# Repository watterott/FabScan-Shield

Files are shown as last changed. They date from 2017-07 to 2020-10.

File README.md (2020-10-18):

# FabScan-Shield
The FabScan-Shield is a plug-on module for Arduino to drive Stepper and Servo Motors or to build a 3D Laser Scanner.

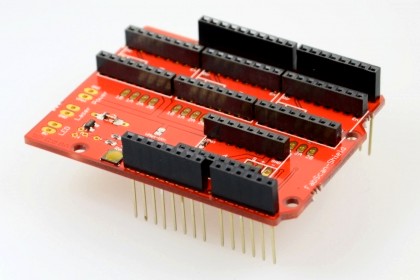
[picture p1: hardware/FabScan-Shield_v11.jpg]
FabScan-Shield


* Drive up to 4 stepper motors (requires Pololu A4988 or StepStick) or servo motors
* Open-Source and released under the [Creative Commons Attribution Share-Alike License](https://creativecommons.org/licenses/by-sa/4.0/).
* **[Documentation on learn.watterott.com](https://learn.watterott.com)**

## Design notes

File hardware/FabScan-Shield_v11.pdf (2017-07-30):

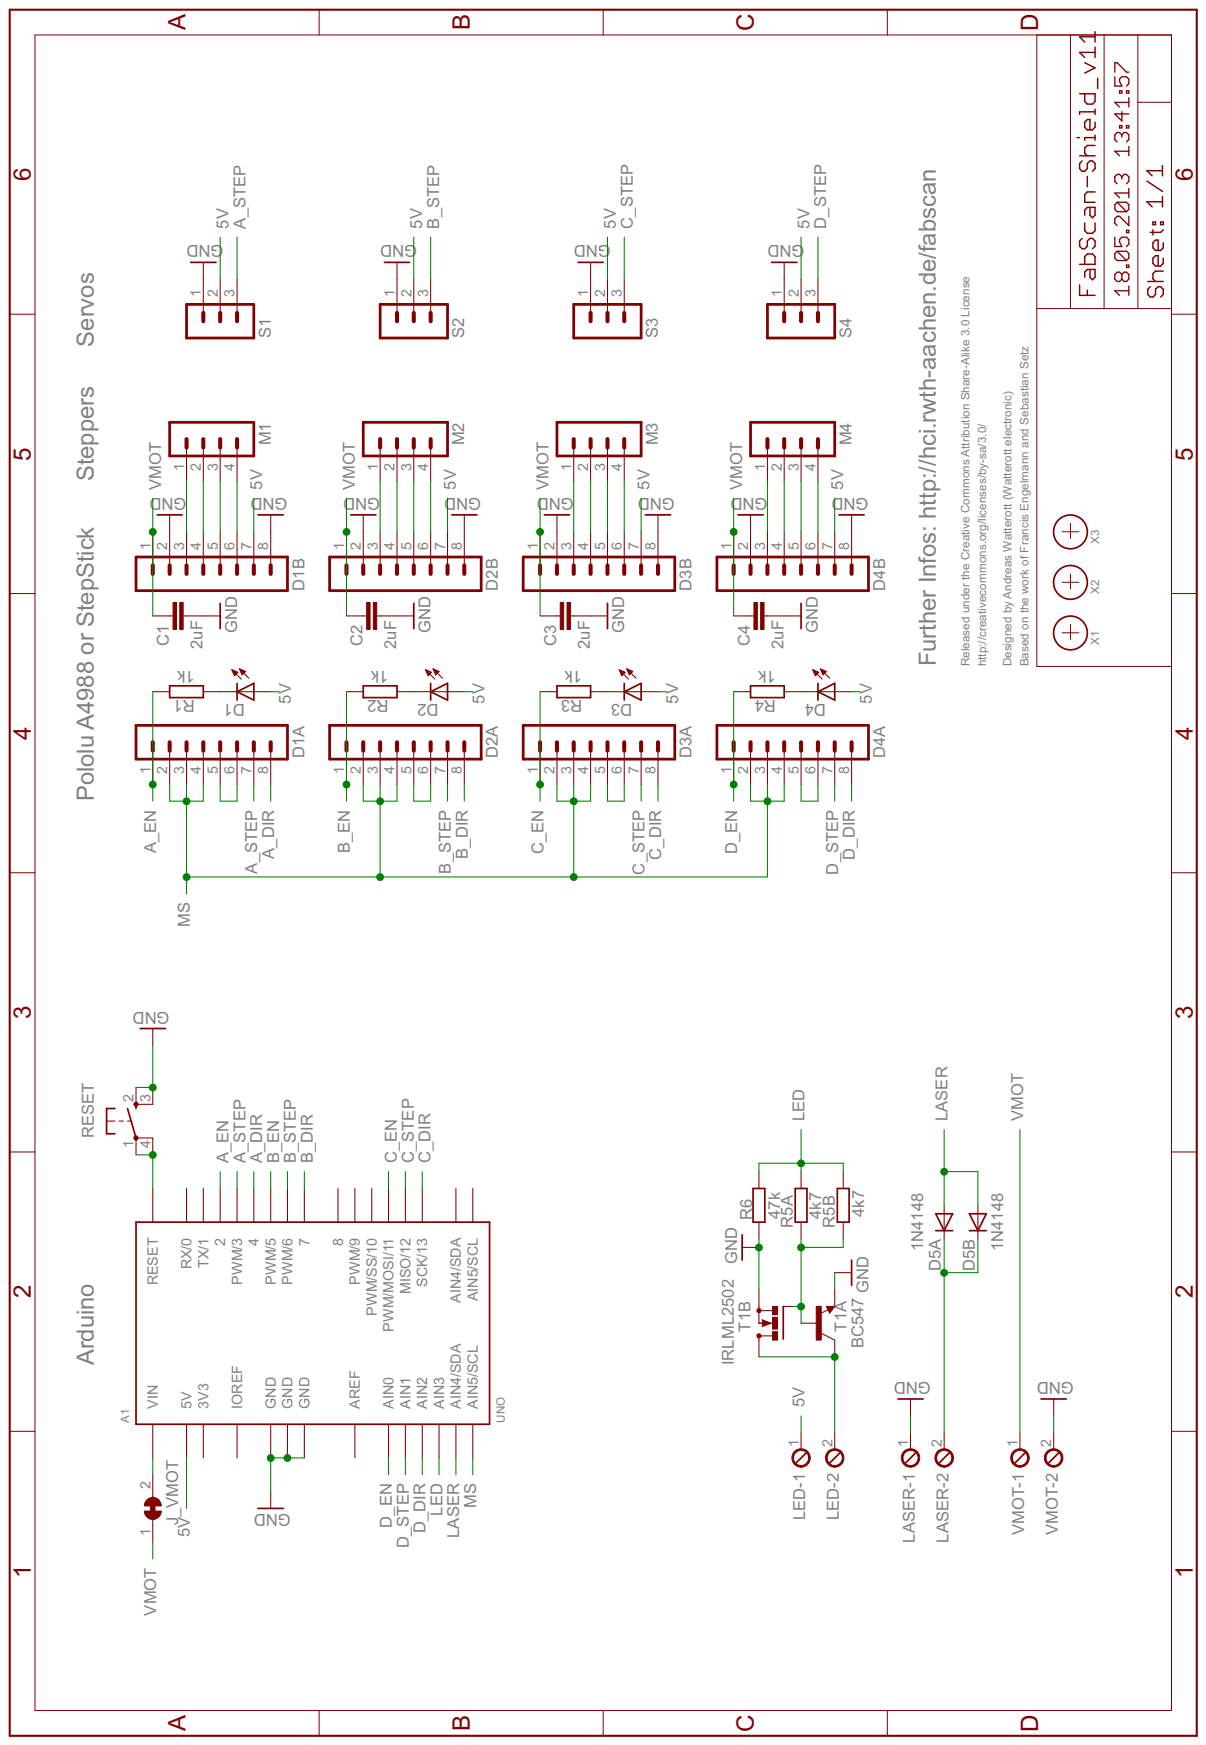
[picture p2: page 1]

Further Infos: http://hci.rwth-aachen.de/fabscan

Servos Steppers Arduino Pololu A4988 or StepStick

Released under the Creative Commons Attribution Share-Alike 3.0 License

Based on the work of Francis Engelmann and Sebastian Setz

Designed by Andreas Watterott (Watterott electronic)

http://creativecommons.org/licenses/by-sa/3.0/

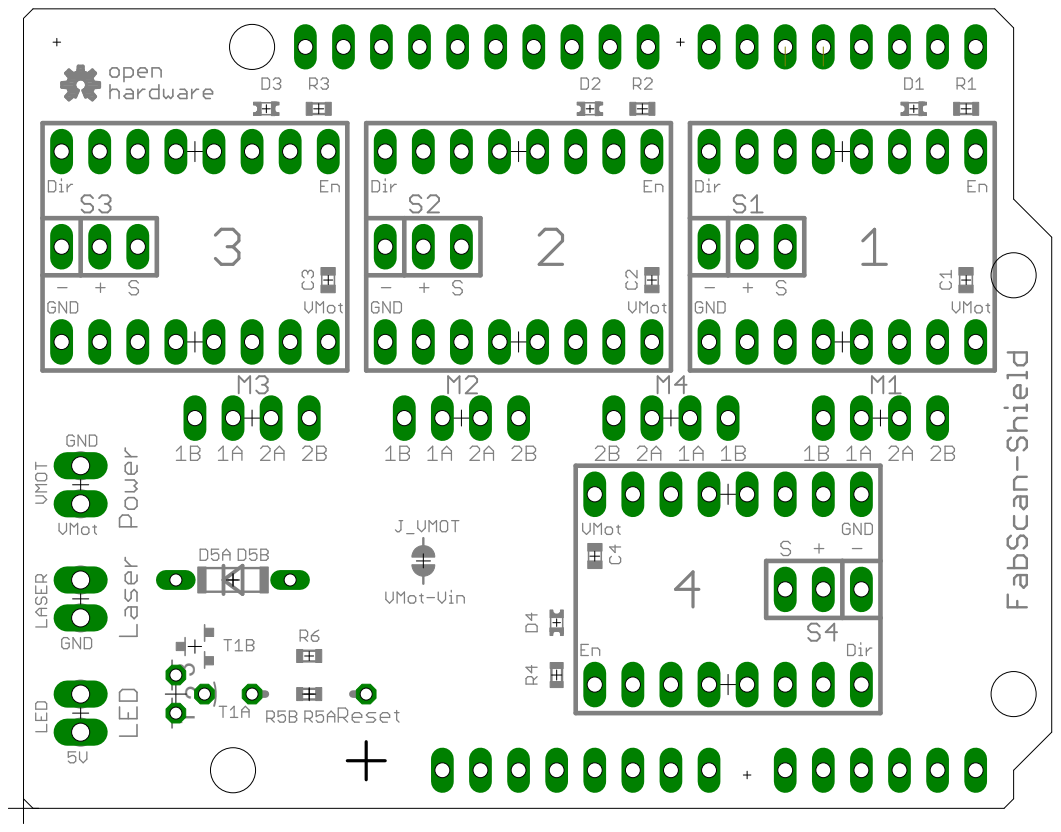
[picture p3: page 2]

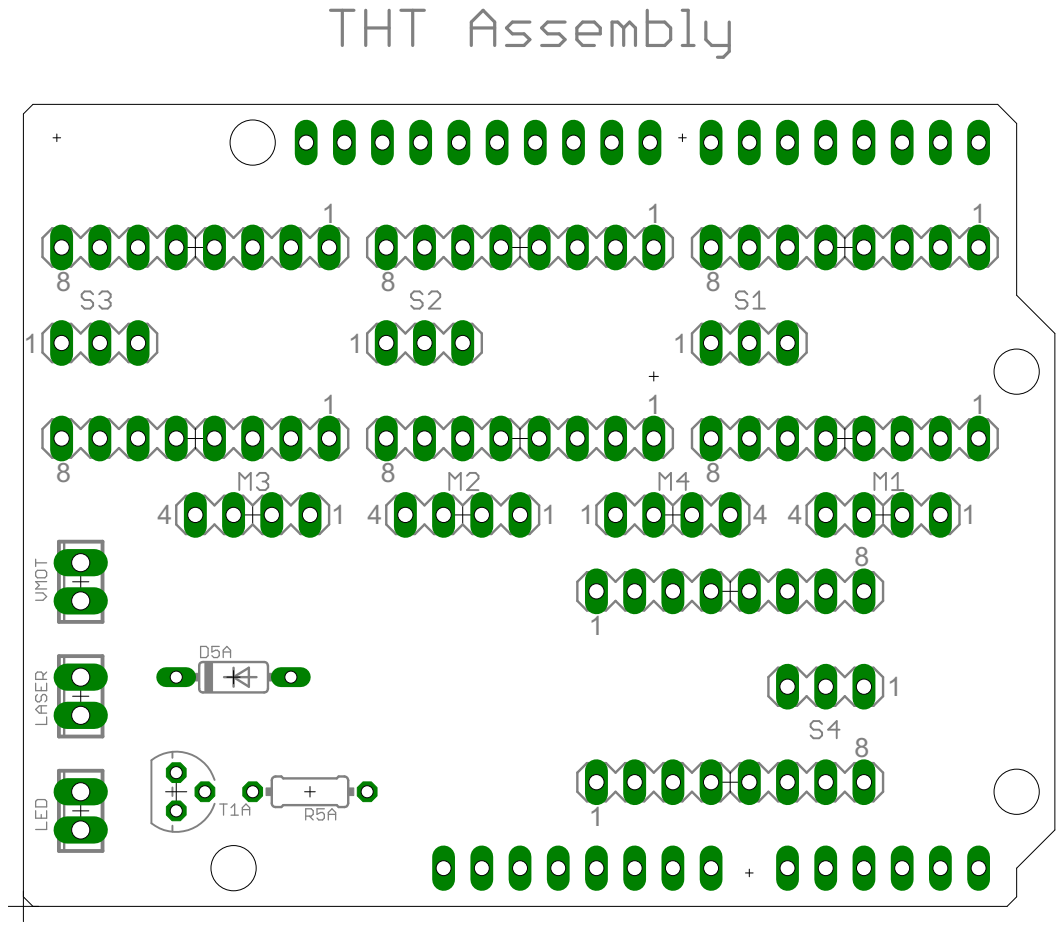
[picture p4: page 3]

# Assembly Guide

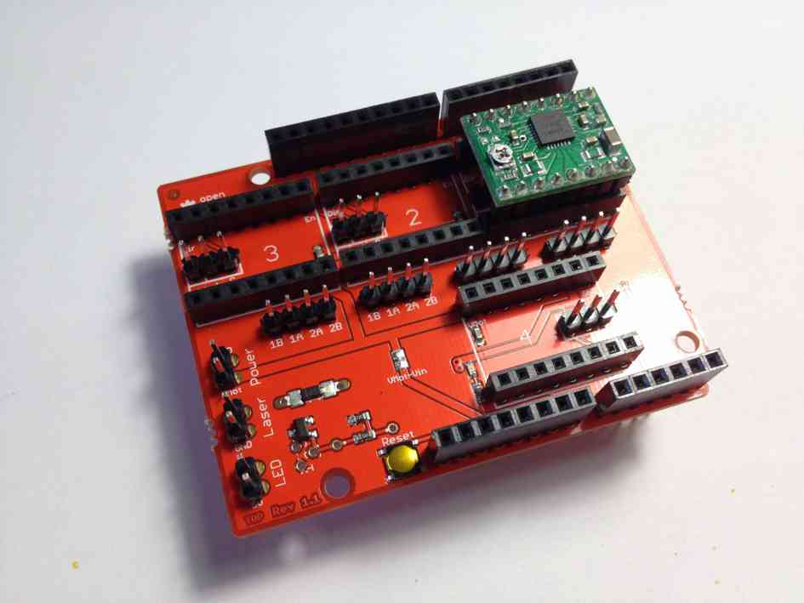
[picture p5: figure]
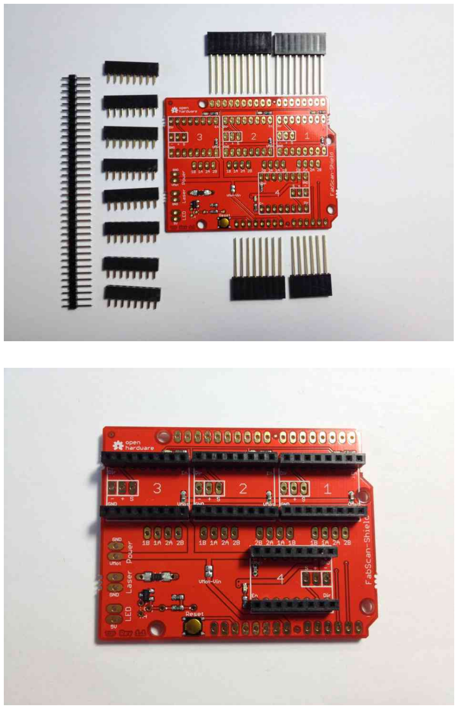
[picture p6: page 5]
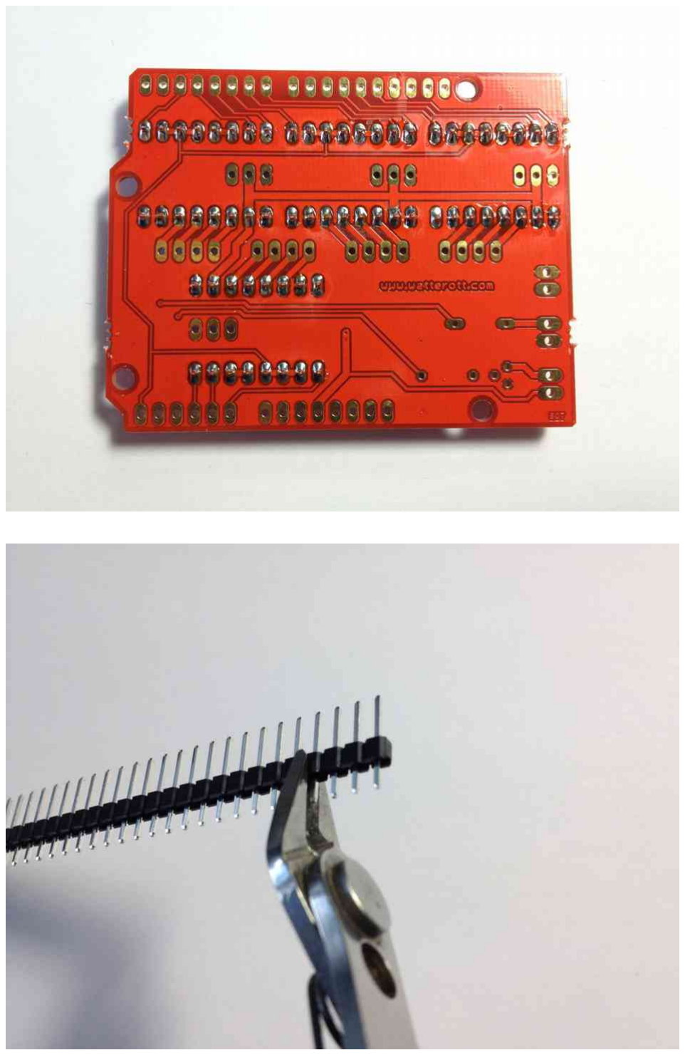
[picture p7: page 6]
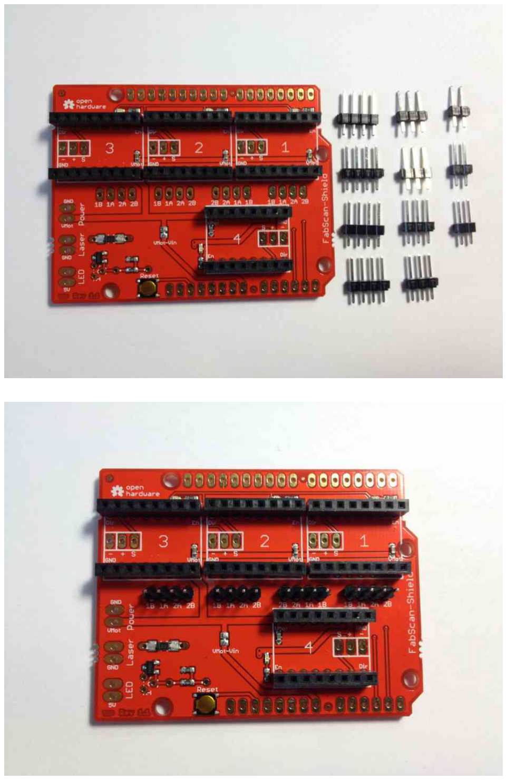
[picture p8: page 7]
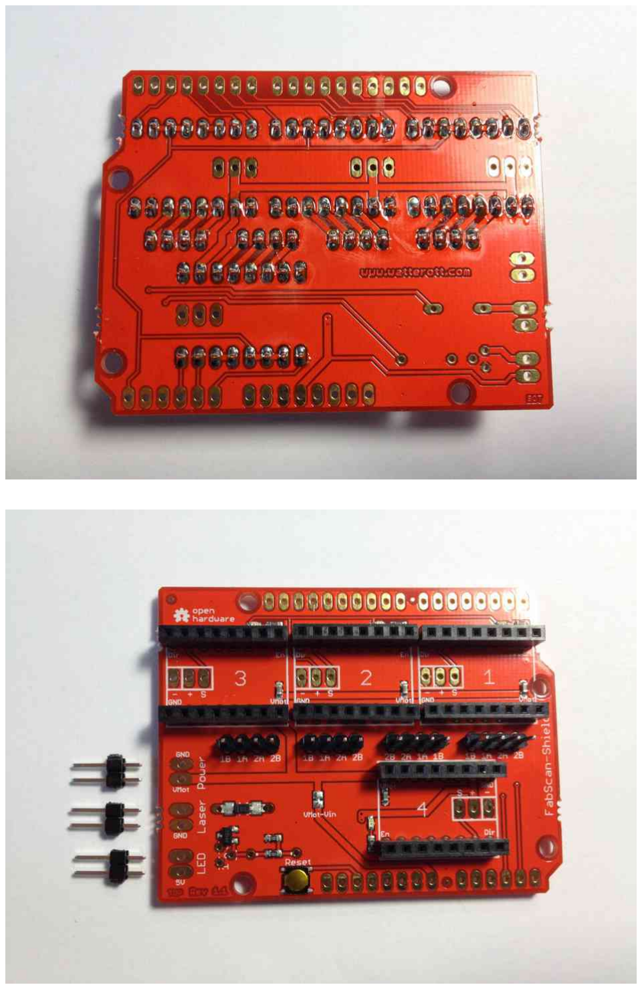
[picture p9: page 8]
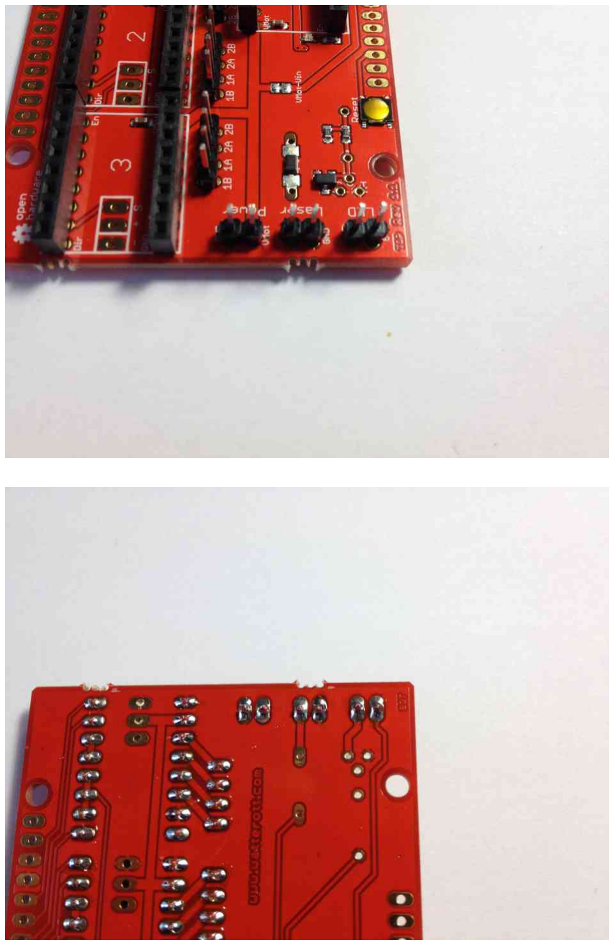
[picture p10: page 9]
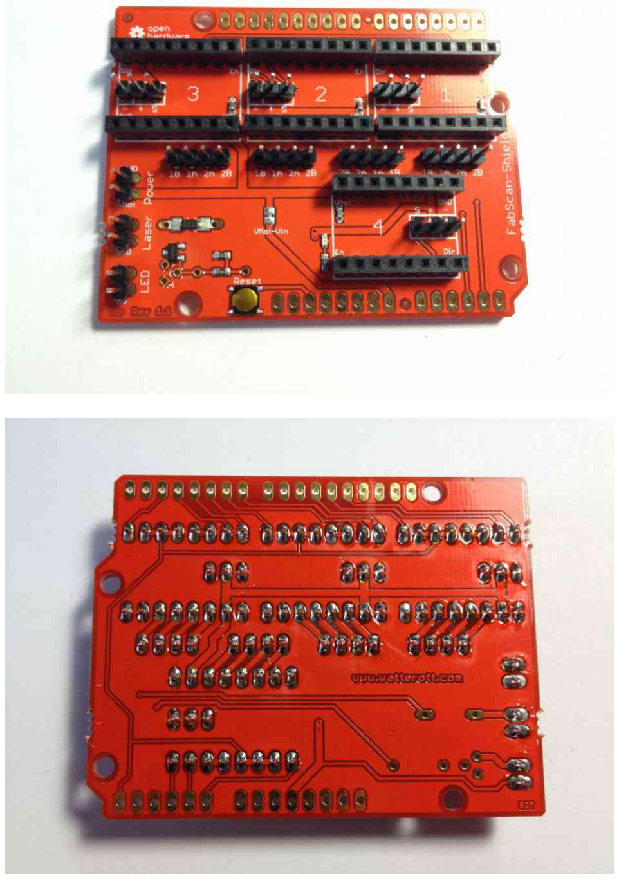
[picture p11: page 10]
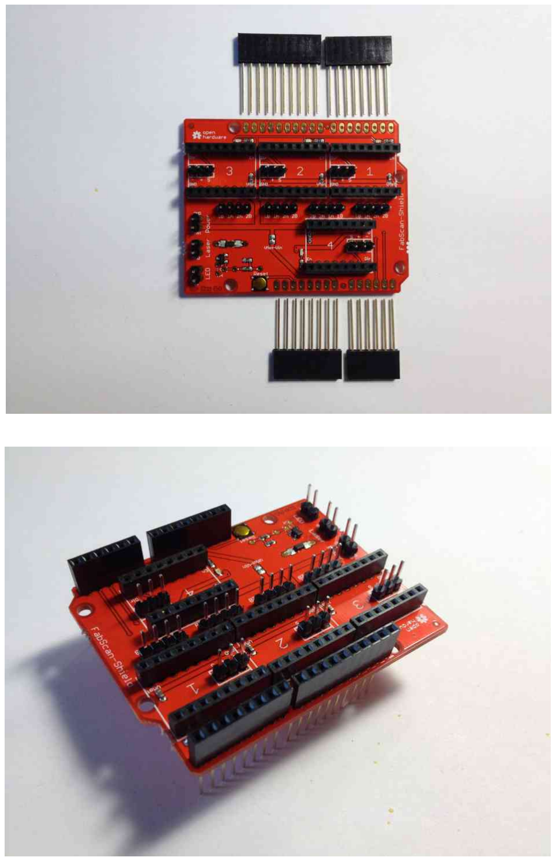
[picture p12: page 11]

# SilentStepStick

# Pin configuration for steahlChop mode with 16 microsteps

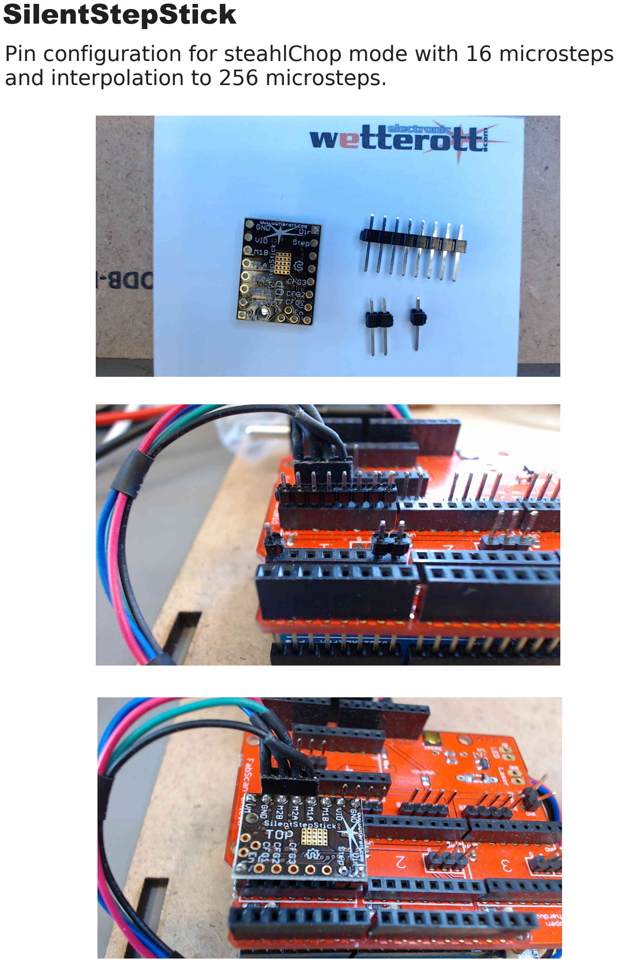
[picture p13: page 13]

and interpolation to 256 microsteps.

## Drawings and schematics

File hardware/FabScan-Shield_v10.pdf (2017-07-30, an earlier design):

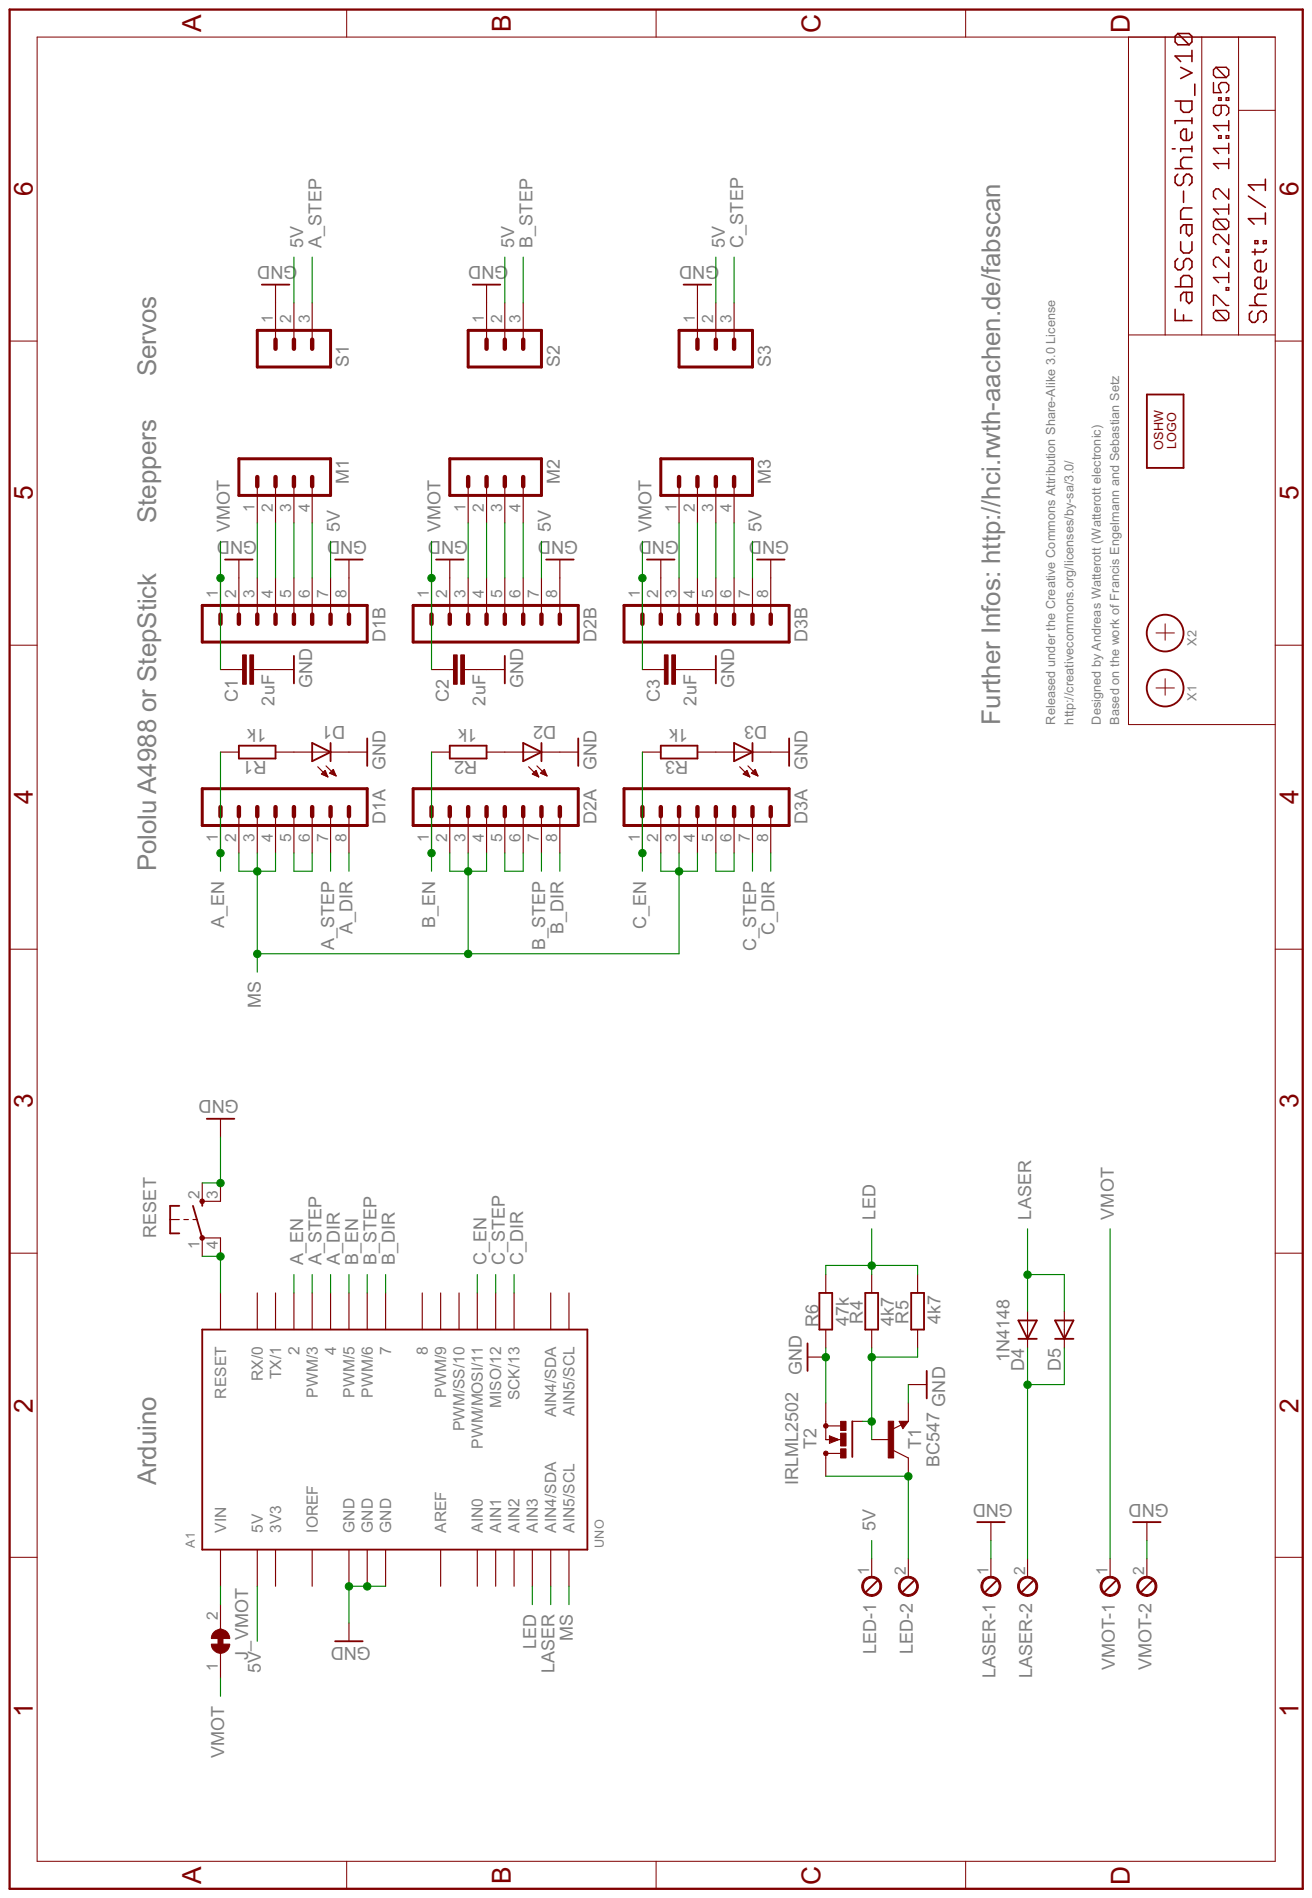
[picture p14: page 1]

Released under the Creative Commons Attribution Share-Alike 3.0 License

Based on the work of Francis Engelmann and Sebastian Set

http://creativecommons.org/licenses/by-sa/3.0/ Designed by Andreas Watterott (Watterott electronic) F

8 PWM/9 PWM/SS/10 PWM/MOSI/11 MISO/12 SCK/13 AIN1 AIN2 AIN3 AIN4/SDA

IOREF GND GND GND

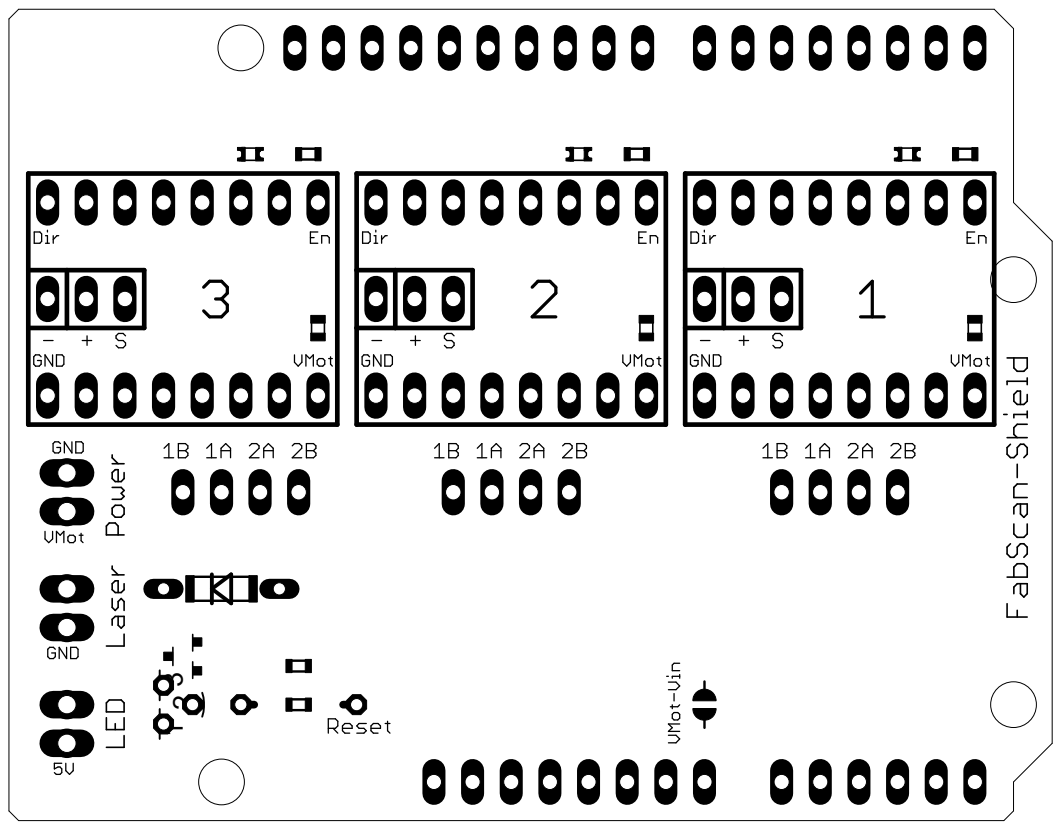
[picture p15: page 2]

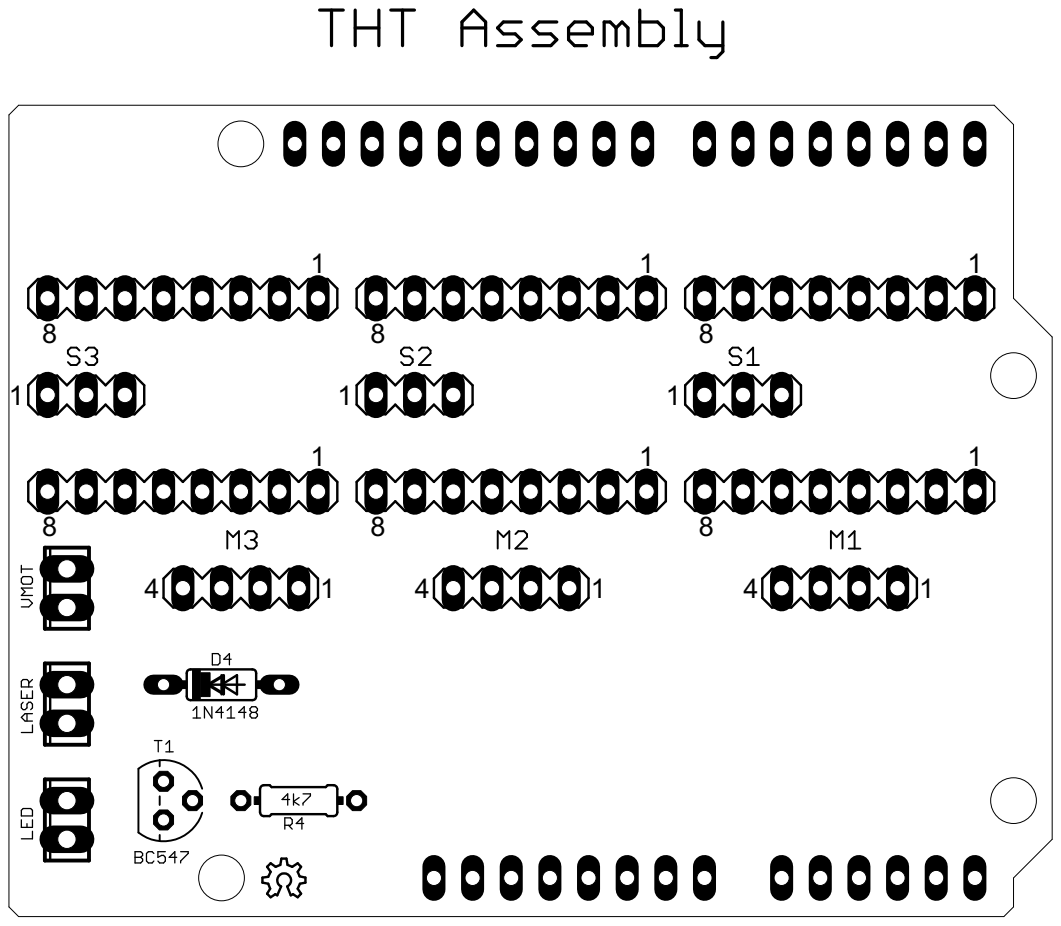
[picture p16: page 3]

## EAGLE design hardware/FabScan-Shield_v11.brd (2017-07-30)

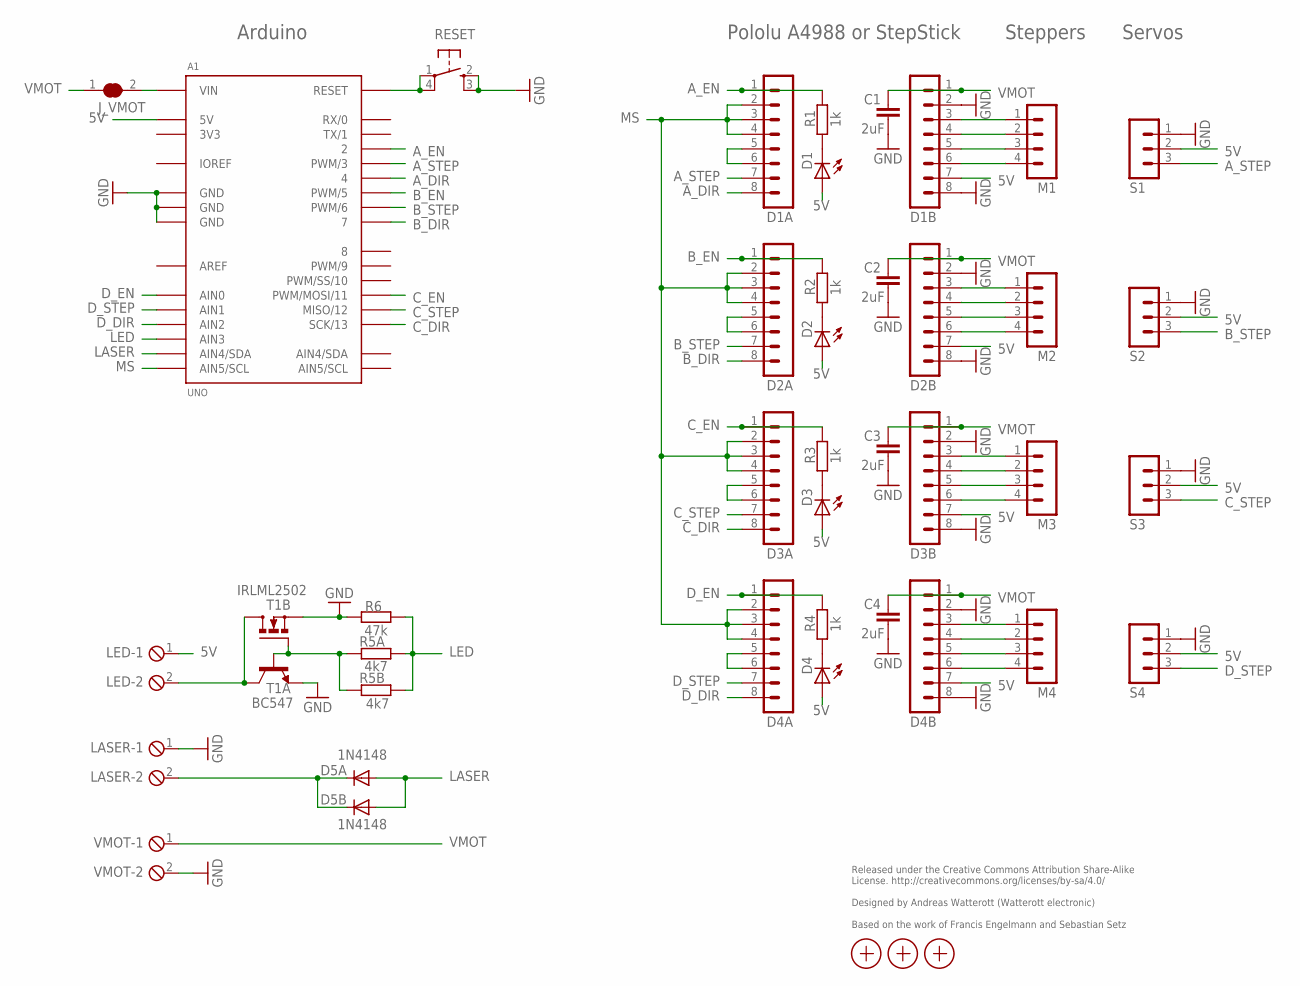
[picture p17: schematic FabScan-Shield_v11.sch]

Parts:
A1: UNO
C1, C2, C3, C4: 2uF; C0603
D1, D2, D3, D4: LEDCHIPLED_0603; CHIPLED_0603
D1A, D1B, D2A, D2B, D3A, D3B, D4A, D4B: MA08-1
D5A: 1N4148; DO35-7
D5B: 1N4148; SOD106-R
J_VMOT: SJ
LASER: MPT2; 2POL254
LED: MPT2; 2POL254
M1, M2, M3, M4: MA04-1
R1, R2, R3, R4: 1k; R0603
R5A: 4k7; 0204/7
R5B: 4k7; R0603
R6: 47k; R0603
RESET: SW_SMDS; SW_SMD4
S1, S2, S3, S4: MA03-1
T1A: BC547; TO92
T1B: IRLML2502; MICRO3
VMOT: MPT2; 2POL254
X1, X2, X3: PASSER

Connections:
3V3: A1.3V3
5V: A1.5V, D1.A, D1B.7, D2.A, D2B.7, D3.A, D3B.7, D4.A, D4B.7, LED.1, S1.2, S2.2, S3.2, S4.2
AREF: A1.AREF
A_1A: D1B.5, M1.3
A_1B: D1B.6, M1.4
A_2A: D1B.4, M1.2
A_2B: D1B.3, M1.1
A_DIR: A1.4, D1A.8
A_EN: A1.2, D1A.1, R1.1
A_RST: D1A.5, D1A.6
A_STEP: A1.3 (PWM/3), D1A.7, S1.3
B_1A: D2B.5, M2.3
B_1B: D2B.6, M2.4
B_2A: D2B.4, M2.2
B_2B: D2B.3, M2.1
B_DIR: A1.7, D2A.8
B_EN: A1.5 (PWM/5), D2A.1, R2.1
B_STEP: A1.6 (PWM/6), D2A.7, S2.3
C_1A: D3B.5, M3.3
C_1B: D3B.6, M3.4
C_2A: D3B.4, M3.2
C_2B: D3B.3, M3.1
C_DIR: A1.13 (SCK/13), D3A.8
C_EN: A1.11 (PWM/MOSI/11), D3A.1, R3.1
C_STEP: A1.12 (MISO/12), D3A.7, S3.3
D_1A: D4B.5, M4.3
D_1B: D4B.6, M4.4
D_2A: D4B.4, M4.2
D_2B: D4B.3, M4.1
D_DIR: A1.AIN2, D4A.8
D_EN: A1.AIN0, D4A.1, R4.1
D_STEP: A1.AIN1, D4A.7, S4.3
GND: A1.GND@1 (GND), A1.GND@2 (GND), A1.GND@3 (GND), C1.2, C2.2, C3.2, C4.2, D1B.2, D1B.8, D2B.2, D2B.8, D3B.2, D3B.8, D4B.2, D4B.8, LASER.1, R6.2, RESET.2 (S), RESET.3 (S1), S1.1, S2.1, S3.1, S4.1, T1A.1 (E), T1B.2 (S), VMOT.2
IOREF: A1.IOREF
LASER: A1.AIN4 (AIN4/SDA), D5A.A, D5B.A
LED: A1.AIN3, R5A.1, R5B.2, R6.1
MS: A1.AIN5 (AIN5/SCL), D1A.2, D1A.3, D1A.4, D2A.2, D2A.3, D2A.4, D3A.2, D3A.3, D3A.4, D4A.2, D4A.3, D4A.4
unnamed: D5A.C, D5B.C, LASER.2
unnamed: D1.C, R1.2
unnamed: D2.C, R2.2
unnamed: D3.C, R3.2
unnamed: D4A.5, D4A.6
unnamed: LED.2, T1A.3 (C), T1B.3 (D)
unnamed: D4.C, R4.2
unnamed: R5A.2, R5B.1, T1A.2 (B), T1B.1 (G)
unnamed: D2A.5, D2A.6
unnamed: D3A.5, D3A.6
RST: A1.RST (RESET), RESET.1, RESET.4 (P1)
VIN: A1.VIN, J_VMOT.2
VMOT: C1.1, C2.1, C3.1, C4.1, D1B.1, D2B.1, D3B.1, D4B.1, J_VMOT.1, VMOT.1

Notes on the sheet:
Released under the Creative Commons Attribution Share-Alike License. http://creativecommons.org/licenses/by-sa/4.0/ Designed by Andreas Watterott (Watterott electronic) Based on the work of Francis Engelmann and Sebastian Setz
Servos
Steppers
Arduino
Pololu A4988 or StepStick

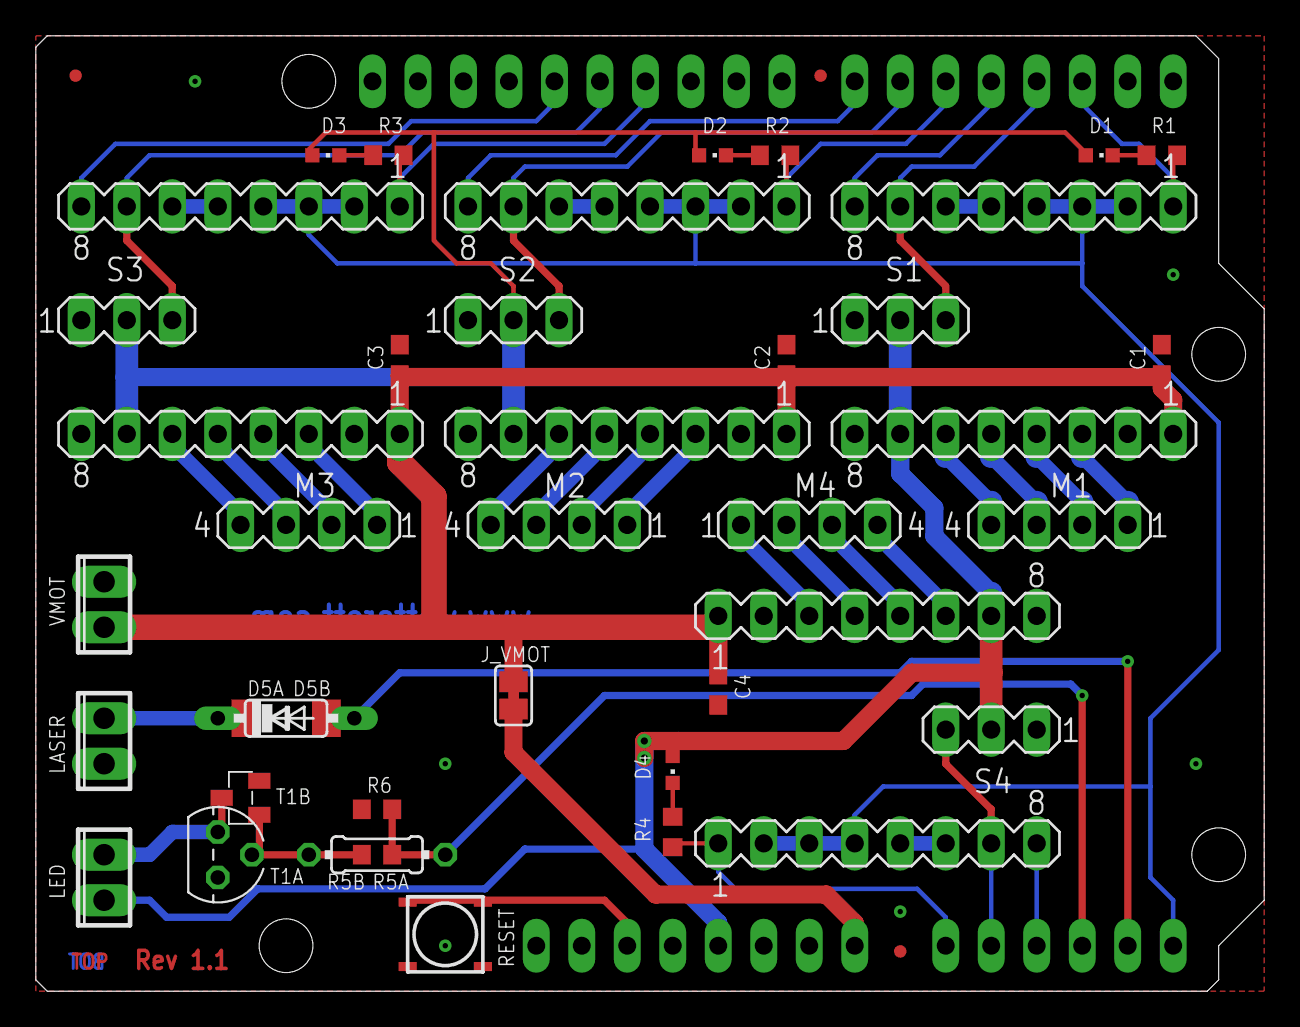
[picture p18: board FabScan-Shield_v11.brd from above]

Board: 2 copper layers, 68.6 x 53.3 mm, 44 parts (0 on the bottom side), 47 nets.

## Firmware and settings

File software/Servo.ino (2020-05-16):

/*
  Using a Servo Motor with FabScan-Shield.
  Further infos: http://arduino.cc/en/Reference/Servo

  Example source code free to use.
  Further information: https://learn.watterott.com/license/
*/

#include <Servo.h> 

Servo myservo;

void setup()
{ 
  myservo.attach(3); //3 or 6 or 12 or A1
} 

void loop() 
{ 
  myservo.write(0); //0...180
  delay(2000);
  myservo.write(90);
  delay(2000);
  myservo.write(180);
  delay(2000);
}

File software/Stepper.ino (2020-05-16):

/*
  Using a StepStick or SilentStepStick Stepper Motor Driver with FabScan-Shield.

  Example source code free to use.
  Further information: https://learn.watterott.com/license/
*/

            //driver: 1 | 2 | 3  | 4
#define EN_PIN   2  //2 | 5 | 11 | A0
#define STEP_PIN 3  //3 | 6 | 12 | A1
#define DIR_PIN  4  //4 | 7 | 13 | A2
#define MS_PIN   A5 //HIGH for 16 microstepping, LOW for no microstepping

void setup()
{
  pinMode(EN_PIN, OUTPUT);
  digitalWrite(EN_PIN, HIGH); //deactivate driver (LOW active)
  pinMode(DIR_PIN, OUTPUT);
  digitalWrite(DIR_PIN, LOW); //LOW or HIGH
  pinMode(STEP_PIN, OUTPUT);
  digitalWrite(STEP_PIN, LOW);

  pinMode(MS_PIN, OUTPUT);
  digitalWrite(MS_PIN, LOW); //no microstepping

  digitalWrite(EN_PIN, LOW); //activate driver
}

void loop()
{
  digitalWrite(STEP_PIN, LOW);
  delay(2);
  digitalWrite(STEP_PIN, HIGH);
  delay(2);
}
